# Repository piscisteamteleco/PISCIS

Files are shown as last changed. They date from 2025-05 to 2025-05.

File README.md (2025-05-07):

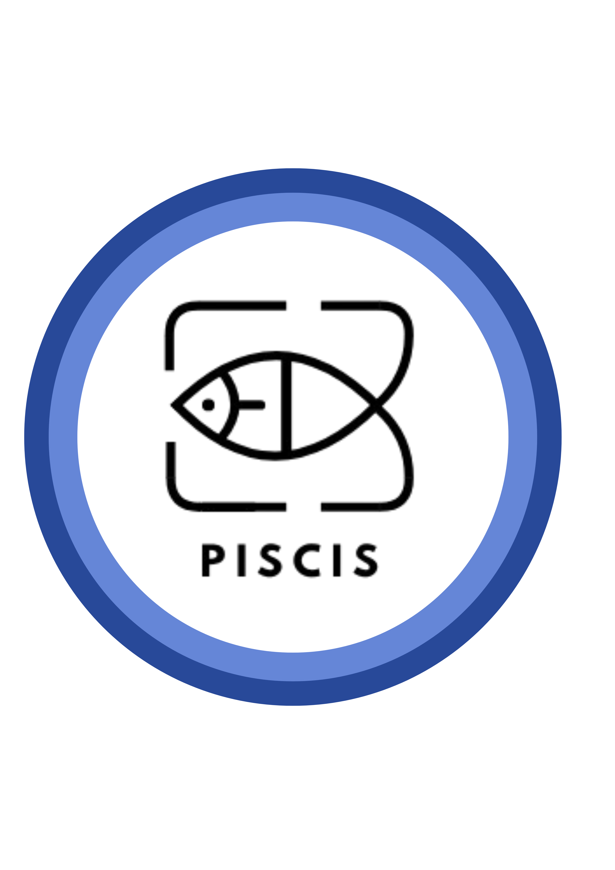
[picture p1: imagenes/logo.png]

**Proyecto Piscis - Sistema de Acuaponia**

**Introducción**
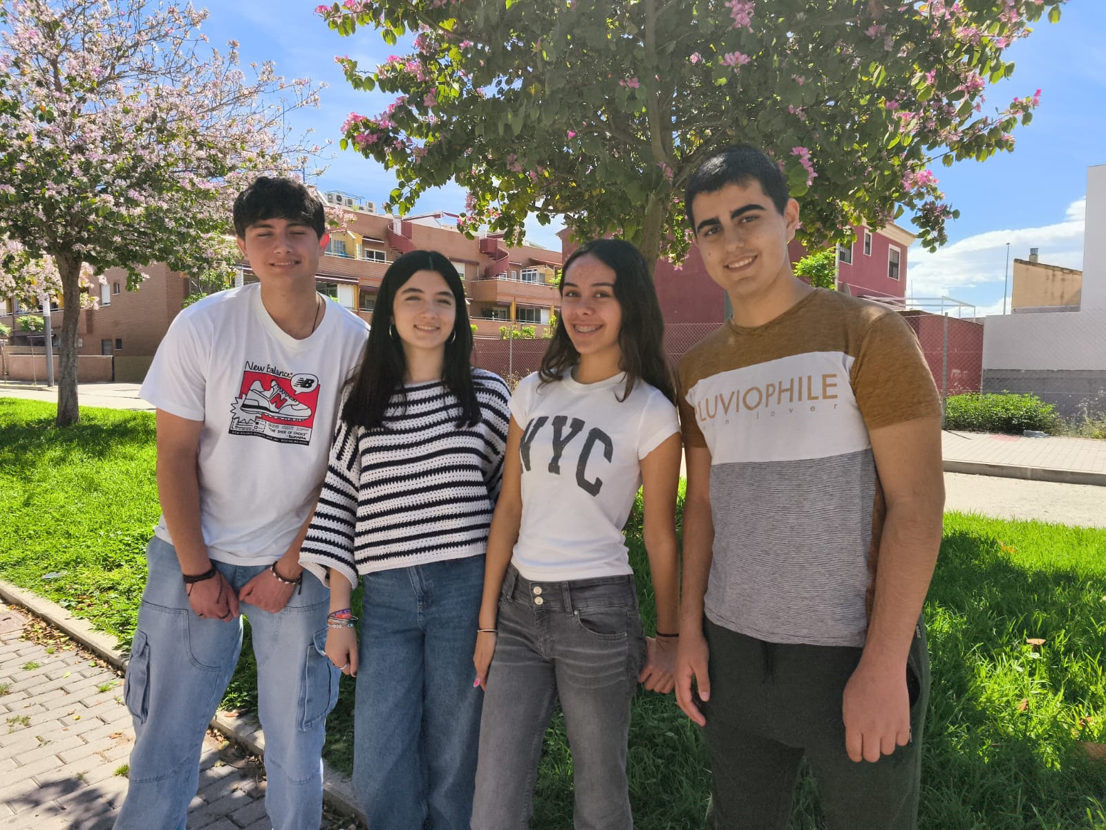
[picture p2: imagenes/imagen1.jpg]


Hola,

Somos PISCISTELECO y, en este documento, iremos dando un breve resumen de nuestro proyecto. Piscis es un proyecto creado para el concurso de telecomunicaciones TELECO GAMES 2025.
Nuestro objetivo es desarrollar un sistema innovador basado en acuaponia que optimice la producción de alimentos de manera sostenible.
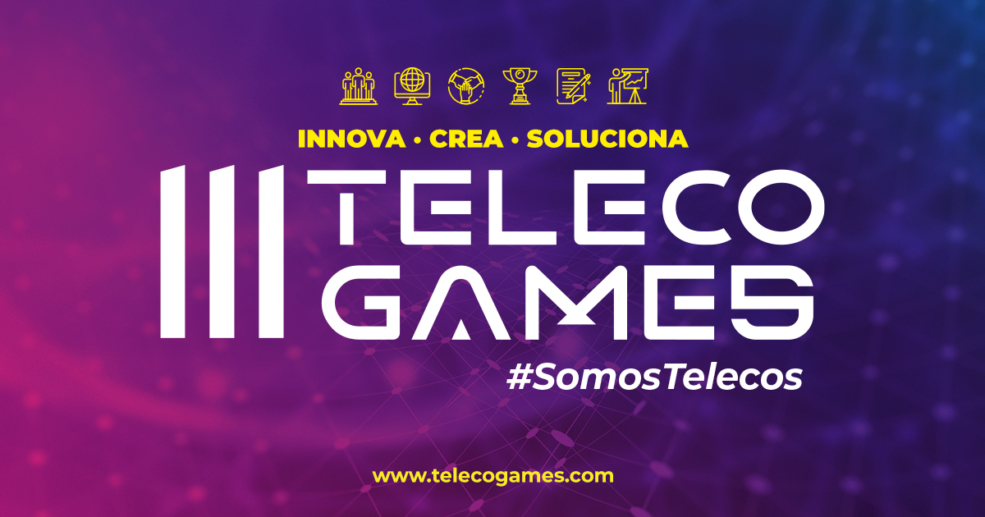
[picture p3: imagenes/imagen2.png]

**¿Qué es un sistema de acuaponia?**

Un sistema de acuaponia es una combinación de acuicultura (cría de peces) e hidroponía (cultivo de plantas sin suelo). Este método permite el crecimiento simultáneo de peces y plantas en un entorno controlado, en el que los desechos de los peces proporcionan nutrientes esenciales para las plantas, mientras que estas purifican el agua, creando un ciclo cerrado y eficiente.

**Funcionamiento del sistema**

Nuestro sistema de acuaponia se basa en los siguientes componentes:
1. **Pecera:** Donde los peces crecen y generan residuos ricos en amoníaco.
2. **Plantas:** Convierte el amoníaco en nitratos, una forma de nutriente absorbible por las plantas.
3. **Sistema de cultivo hidropónico:** Donde las plantas absorben los nutrientes y purifican el agua.

**Beneficios del sistema de acuaponia**

- **Sostenibilidad:** Reduce el consumo de agua y elimina la necesidad de fertilizantes químicos.
- **Eficiencia:** Optimiza el uso de recursos, permitiendo una producción más rápida y saludable.
- **Automatización y control inteligente:** Uso de sensores y dispositivos IoT para la monitorización remota y ajuste automático de las condiciones del sistema.
- **Versatilidad:** Puede aplicarse en entornos urbanos, rurales y domésticos, promoviendo la autosuficiencia alimentaria.
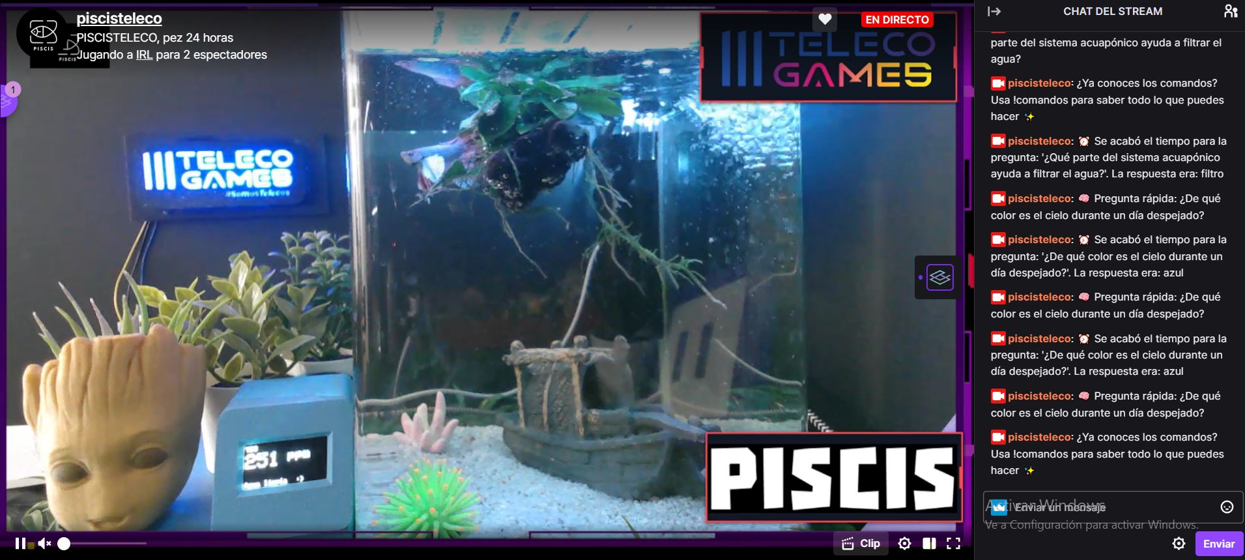
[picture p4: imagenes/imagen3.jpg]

**Conclusión**

Piscis es un ecosistema donde peces, plantas y tecnología conviven en armonía.
Hemos demostrado que las telecomunicaciones pueden conectar no solo datos, sino también vida, sostenibilidad y conciencia.
Y lo hacemos en directo, las 24 horas, compartiendo conocimiento con el mundo.

Porque para nosotros, conectar no es solo una cuestión de cables…
 
**Equipo PISCISTELECO**

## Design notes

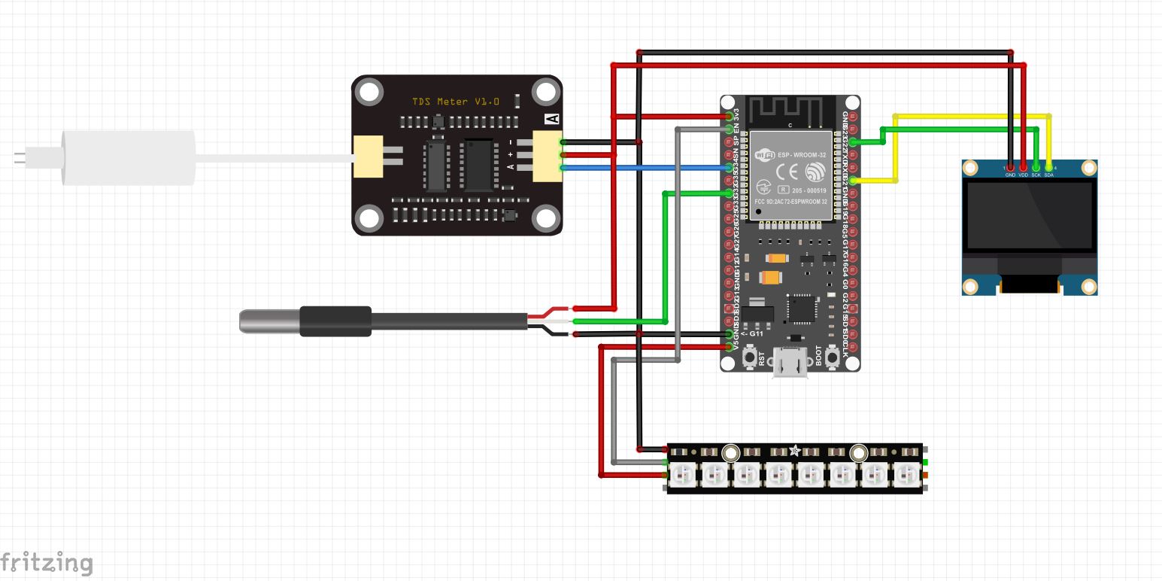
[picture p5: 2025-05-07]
Esquema electrico/esquemapiscis.JPG

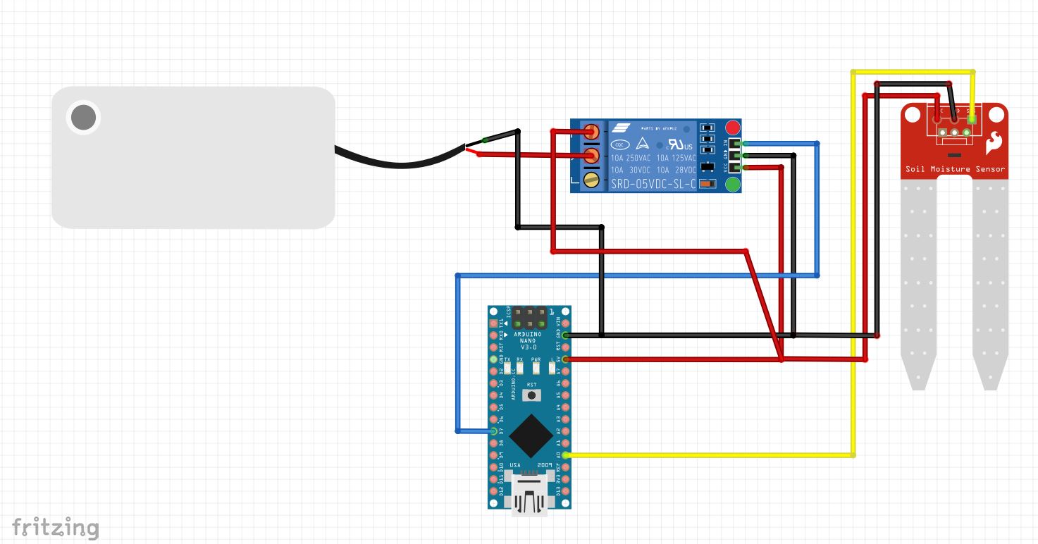
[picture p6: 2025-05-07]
Esquema electrico/esquemapiscis2.JPG

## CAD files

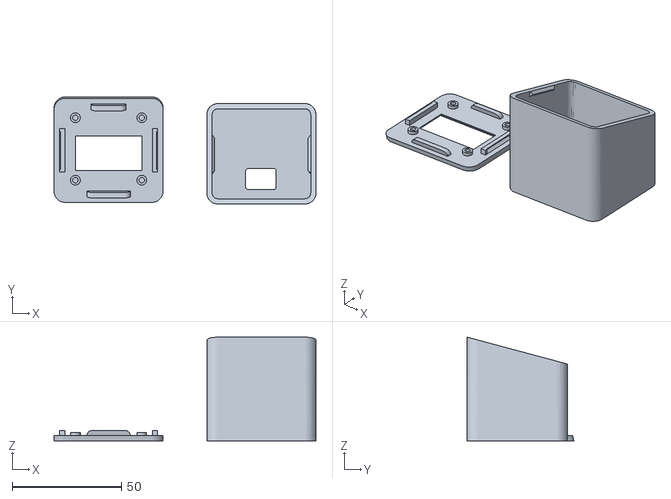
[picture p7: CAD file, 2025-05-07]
diseños 3D/pantallaoled.stl
120.0 x 49.0 x 47.5

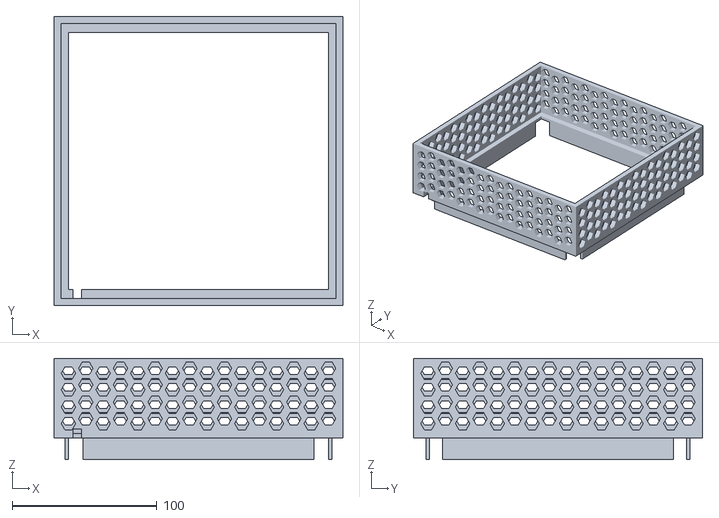
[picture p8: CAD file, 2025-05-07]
diseños 3D/cesta.stl
200.0 x 200.0 x 70.0

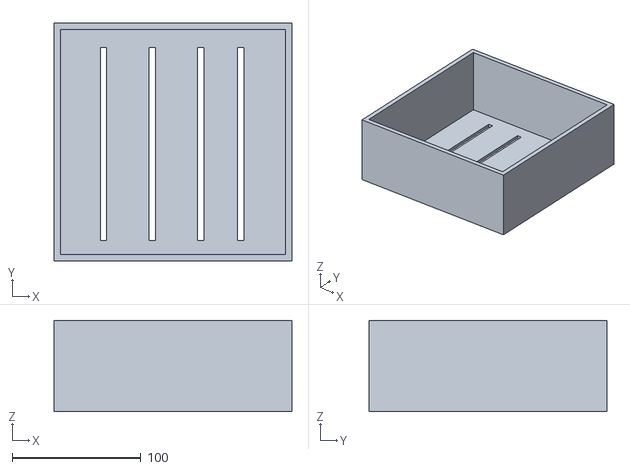
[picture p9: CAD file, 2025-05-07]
diseños 3D/macetero.stl
185.0 x 185.0 x 71.0

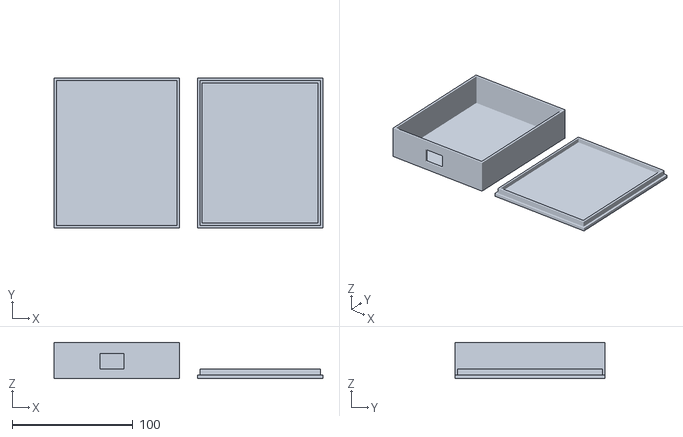
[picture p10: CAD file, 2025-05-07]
diseños 3D/cajacomponentes.stl
223.0 x 124.0 x 30.0

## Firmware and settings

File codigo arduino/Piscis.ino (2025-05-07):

/**************************************************************************
  Ejemplo completo ESP32:
  - Mide TDS (sensor analógico) y temperatura (DS18B20)
  - Compensa TDS según temperatura
  - Sube TDS y temperatura a ThingSpeak (fields 1 y 2) cada 15 s
  - Lee un comando de color de ThingSpeak (field 3): RRGGBB o “RAINBOW”
  - Enciende una tira WS2812B con Adafruit_NeoPixel según el comando
  - Muestra alternadamente en OLED la lectura de TDS y de temperatura
**************************************************************************/

// ——————————— INCLUYE LIBRERÍAS ———————————
#include <WiFi.h>                // Conexión Wi-Fi
#include <HTTPClient.h>          // Cliente HTTP para leer ThingSpeak
#include <ThingSpeak.h>          // Biblioteca ThingSpeak (para escribir)
#include <OneWire.h>             // Comunicación 1-Wire (DS18B20)
#include <DallasTemperature.h>   // Lectura de DS18B20
#include <Wire.h>                // I2C para OLED
#include <Adafruit_GFX.h>        // Gráficos base para OLED
#include <Adafruit_SH110X.h>     // Driver para pantallas SH1106/SH1107
#include <Adafruit_NeoPixel.h>   // Control de tira WS2812B

// —————— 1) CREDENCIALES Y PARÁMETROS ——————
const char* ssid        = "mmmacademyAP";              // Nombre de tu red Wi-Fi
const char* password    = "MMMacademy2021";              // Contraseña de tu Wi-Fi

// ThingSpeak: canal y claves
const unsigned long channelID   = 2833025;        // ID de tu canal
const char* writeAPIKey          = "8S422K718DH5XBQW";  // Para escribir fields 1 y 2
const char* readAPIKey           = "78JUDN4L97ZJEZ3V";   // Si el canal es privado; si no, deja ""

WiFiClient  tsClient;          // Cliente para ThingSpeak (escritura)

// —————— 2) DEFINICIONES DE PINES ——————
#define TDS_PIN     34         // Pin analógico donde va el sensor TDS
#define ONE_WIRE_PIN 32        // Pin digital DATA del DS18B20
#define OLED_SDA    21         // Pin SDA para OLED (I2C)
#define OLED_SCL    22         // Pin SCL para OLED (I2C)
#define LED_PIN     2         // Pin de datos de la tira WS2812B
#define NUM_LEDS    30         // Número total de LEDs en la tira

// —————— 3) OBJETOS GLOBALES ——————

OneWire oneWire(ONE_WIRE_PIN);                 // Bus OneWire para DS18B20
DallasTemperature sensors(&oneWire);           // Objeto sensor DS18B20

Adafruit_SH1106G display(128, 64, &Wire, -1);  // Pantalla OLED SH1106 128×64

Adafruit_NeoPixel strip(NUM_LEDS, LED_PIN, NEO_GRB + NEO_KHZ800);
// strip.begin() y strip.show() se llaman en setup()

// ThingSpeak timing
unsigned long lastTSWrite = 0;
const unsigned long TS_INTERVAL = 15000;  // 15.000 ms mínimo entre escrituras

// —————— 4) FUNCIONES AUXILIARES ——————

/**
 * Wheel(pos):
 *  Genera un color del arcoíris (255 colores).
 *  pos: valor de 0 a 255
 *  Devuelve un uint32_t con el color RGB empaquetado.
 */
uint32_t Wheel(uint8_t pos) {
  pos = 255 - pos;
  if (pos < 85)  return strip.Color(255 - pos * 3, 0, pos * 3);
  if (pos < 170) { pos -= 85; return strip.Color(0, pos * 3, 255 - pos * 3); }
                  pos -= 170;
  return strip.Color(pos * 3, 255 - pos * 3, 0);
}

/**
 * showRainbow():
 *  Recorre todos los LEDs y aplica un degradado arcoíris
 */
void showRainbow() {
  for (int i = 0; i < NUM_LEDS; i++) {
    // Distribuye los 256 tonos equitativamente en la tira
    uint8_t idx = (i * 256) / NUM_LEDS;
    strip.setPixelColor(i, Wheel(idx));
  }
  strip.show();
}

// —————— 5) setup(): configuración inicial ——————
void setup() {
  // Serial para debug
  Serial.begin(115200);
  delay(100);

  // 5.1 Conectar a Wi-Fi
  WiFi.begin(ssid, password);
  Serial.print("Conectando WiFi");
  while (WiFi.status() != WL_CONNECTED) {
    delay(500);
    Serial.print(".");
  }
  Serial.println();
  Serial.print("IP ESP32: ");
  Serial.println(WiFi.localIP());

  // 5.2 Inicializar ThingSpeak (escritura)
  ThingSpeak.begin(tsClient);

  // 5.3 Inicializar NeoPixel
  strip.begin();      // Configura pin y buffers
  strip.show();       // Apaga todos al arrancar

  // 5.4 Inicializar sensores y pantalla OLED
  sensors.begin();    // DS18B20
  Wire.begin(OLED_SDA, OLED_SCL); // I2C para OLED
  delay(250);
  display.begin(0x3C, true);      // Dirección 0x3C, sin reset pin
  display.setTextColor(SH110X_WHITE);
}

// —————— 6) loop(): bucle principal ——————
void loop() {
  // 6.1) Medir temperatura con DS18B20
  sensors.requestTemperatures();
  float tempC = sensors.getTempCByIndex(0);  // °C

  // 6.2) Leer sensor TDS (voltaje) y convertir a ppm
  int analogValue = analogRead(TDS_PIN);
  float voltage   = analogValue * (3.3 / 4095.0);
  float tdsRaw    = (133.42 * pow(voltage, 3)
                   - 255.86 * pow(voltage, 2)
                   
                   + 857.39 * voltage) * 0.5;
  // Compensación por temperatura (ref 25 °C, coef 2%/°C)
  int tdsInt = round(tdsRaw / (1.0 + 0.02 * (tempC - 25.0)));

  // 6.3) Escribir TDS y Temp en ThingSpeak cada 15 s
  if (millis() - lastTSWrite >= TS_INTERVAL) {
    ThingSpeak.setField(1, tdsInt);    // Field 1 = TDS (ppm)
    ThingSpeak.setField(2, tempC);     // Field 2 = Temp (°C)
    int resp = ThingSpeak.writeFields(channelID, writeAPIKey);
    Serial.print("ThingSpeak write result: ");
    Serial.println(resp);
    lastTSWrite = millis();
  }

  // 6.4) Leer comando de color (field 3) desde ThingSpeak
  String cmd;
  {
    HTTPClient http;
    String url = String("http://api.thingspeak.com/channels/") +
                 channelID + "/fields/3/last.txt";
    if (strlen(readAPIKey) > 0) {
      url += "?api_key=" + String(readAPIKey);
    }
    http.begin(url);
    int httpCode = http.GET();
    if (httpCode == 200) {
      cmd = http.getString();
      cmd.trim();  // Elimina espacios y saltos de línea
    }
    http.end();
  }
  Serial.print("Comando leido: ");
  Serial.println(cmd);

  // 6.5) Interpretar comando y cambiar LEDs
  if (cmd.equalsIgnoreCase("RAINBOW")) {
    // Efecto arcoíris
    showRainbow();
  }
  else if (cmd.length() == 6) {
    // Asume un hex RRGGBB
    long val = strtol(cmd.c_str(), NULL, 16);
    uint8_t r = (val >> 16) & 0xFF;
    uint8_t g = (val >>  8) & 0xFF;
    uint8_t b =  val        & 0xFF;
    // Pintar todos los LEDs con ese color
    for (int i = 0; i < NUM_LEDS; i++) {
      strip.setPixelColor(i, strip.Color(r, g, b));
    }
    strip.show();
  }
  // Si cmd no coincide con nada, mantiene el color anterior

  // 6.6) Mostrar en OLED: lectura de TDS + estado
  String estado, emoji;
  if      (tdsInt < 300) { estado = "Agua limpia"; emoji = ":)"; }
  else if (tdsInt < 600) { estado = "Calidad media"; emoji = ":|"; }
  else                   { estado = "Agua sucia";  emoji = ":("; }

  display.clearDisplay();
  // Línea de título
  display.setTextSize(1);
  display.setCursor(0, 0);
  display.print("TDS");
  // Valor grande
  display.setTextSize(3);
  display.setCursor(0, 12);
  display.print(tdsInt);
  // Unidad
  display.setTextSize(2);
  display.print(" ppm");
  // Estado + emoji en la parte inferior
  display.setTextSize(1);
  display.setCursor(0, 55);
  display.print(estado);
  display.setCursor(80, 55);
  display.print(emoji);
  display.display();

  // Debug serial
  Serial.printf("TDS: %d ppm   %s %s\n", tdsInt, estado.c_str(), emoji.c_str());

  delay(5000);  // Espera 5 s antes de mostrar temperatura

  // 6.7) Mostrar en OLED: lectura de temperatura
  display.clearDisplay();
  display.setTextSize(1);
  display.setCursor(0, 0);
  display.print("Temperatura");
  display.setTextSize(3);
  display.setCursor(0, 12);
  display.print(tempC, 1);
  display.setTextSize(2);
  display.print(" C");
  display.display();

  Serial.printf("Temperatura: %.1f °C\n", tempC);

  delay(5000);  // Espera 5 s antes de repetir el bucle
}
